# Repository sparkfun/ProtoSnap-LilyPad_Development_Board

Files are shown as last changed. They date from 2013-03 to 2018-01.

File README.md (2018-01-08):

ProtoSnap- LilyPad Development Board
====================================

LilyPad Protosnap

[*ProtoSnap-LilyPad Development Board (DEV-11262)*](https://www.sparkfun.com/products/11262)

The ProtoSnap LilyPad Development Board allows you to start prototyping in the world of e-textiles without a breadboard.

Repository Contents
-------------------
* **/Firmware** - LilyPad Development Board's default Arduino example code.
* **/Hardware** - All Eagle design files (.brd, .sch, .STL)

Documentation
-------------------
* [Hookup Guide](https://www.sparkfun.com/tutorials/308) - Basic hookup guide for the LilyPad Development Board.
* [Activity Guide](https://learn.sparkfun.com/tutorials/lilypad-development-board-activity-guide) - This guide will get you started with some introductory programming activities exploring each of the LilyPad pieces on the LilyPad Development Board. If you’ve never used Arduino to program before, this guide will walk you through the basics with example code to upload and explore.

Product Versions
----------------
* [DEV-11262](https://www.sparkfun.com/products/11262)- This is the standard ProtoSnap LilyPad Development Board
* [RTL-11261](https://www.sparkfun.com/products/11261)- Retail version of the ProtoSnap LilyPad Development Board. (Retired)
* [LAB-11762](https://www.sparkfun.com/products/11762)- Packaged version for educators teaching the ProtoShap LilyPad Development Board in a classroom setting. 

License Information
-------------------
The hardware is released under [Creative Commons Share-alike 3.0](http://creativecommons.org/licenses/by-sa/3.0/).

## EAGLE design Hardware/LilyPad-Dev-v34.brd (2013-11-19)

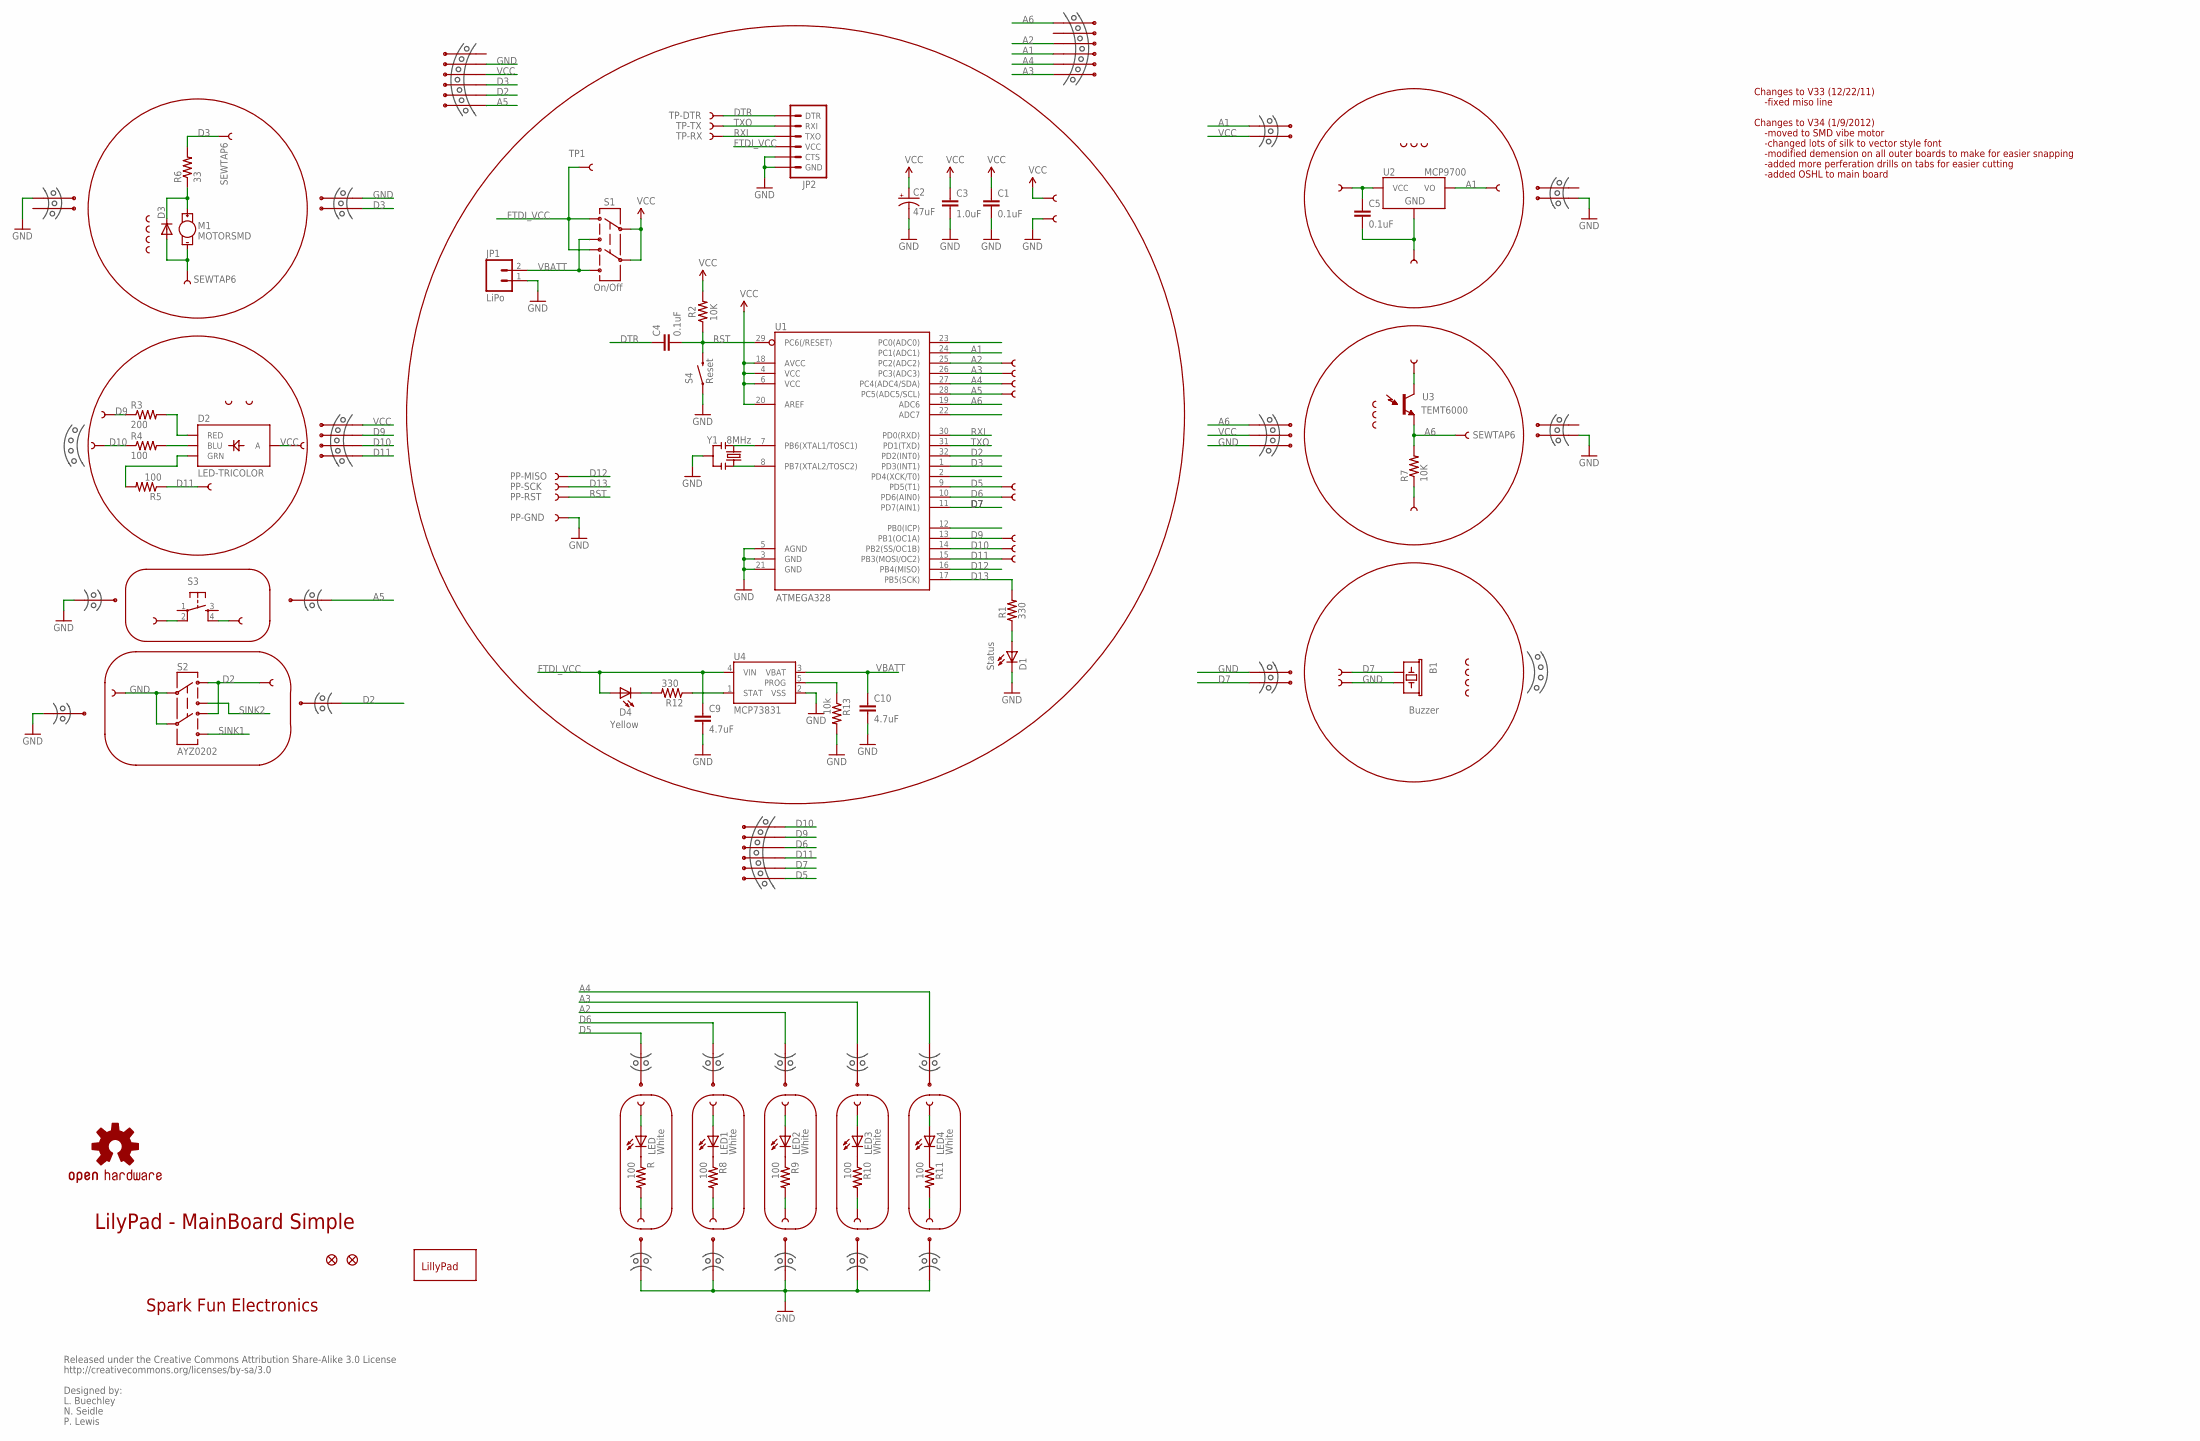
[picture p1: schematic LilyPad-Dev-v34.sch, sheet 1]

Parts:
1, 2, 3, 4: SEWTAP-NOHOLE2; PETAL-NOHOLE-2SIDE
A2/16, A3/17, A4/18, A5/19: SEWTAP9; PETAL-LONG-1-2SIDE
B1: Buzzer; BUZZER-CCV
BUTTON-: SEWTAP8; PETAL-SMALL
BUTTONS: SEWTAP8; PETAL-SMALL
C1, C4: 0.1uF; 0402-CAP
C2: 47uF; EIA3528
C3: 1.0uF; 0402-CAP
C5: 0.1uF; 0603-CAP
C9, C10: 4.7uF; 0402-CAP
D1: Status; LED-0603
D2: LED-TRICOLOR; LED-TRICOLOR-SMD
D3: DIODESOD; SOD-323
D4: Yellow; LED-0603
JP1: LiPo; JST-2-SMD
JP2: ARDUINO_SERIAL_PROGRAMSMD; 1X06-SMD
JP3, JP4: FIDUCIAL1X2; FIDUCIAL-1X2
LED, LED1, LED2, LED3, LED4: White; LED-1206
LED+, LED+1, LED+2, LED+3, LED+4: SEWTAP6; PETAL-SMALL-2SIDE
LED-, LED-1, LED-2, LED-3, LED-4: SEWTAP6; PETAL-SMALL-2SIDE
LIGHT1, LIGHT2, LIGHT3: SEWTAP-NOHOLE2; PETAL-NOHOLE-2SIDE
LIGHT+: SEWTAP6; PETAL-SMALL
LIGHT-: SEWTAP6; PETAL-SMALL
LIGHTS: SEWTAP6; PETAL-SMALL
LOGO: LOGO-LPLPA; LOGO-LPA
M1: MOTORSMD; VIBE-MOTOR-10MM-SMD
PP-GND: TEST-POINT3X5; PAD.03X.05
PP-MISO: TEST-POINT3X5; PAD.03X.05
PP-RST: TEST-POINT3X5; PAD.03X.05
PP-SCK: TEST-POINT3X5; PAD.03X.05
R, R8, R9, R10, R11: 100; 0603-RES
R1, R12: 330; 0402-RES
R2, R7: 10K; 0402-RES
R3: 200; 0402-RES
R4, R5: 100; 0402-RES
R6: 33; 0402-RES
R13: 10k; 0402-RES
S1: On/Off; AYZ0202
S2: AYZ0202
S3: TAC_SWITCHSMD; TACTILE_SWITCH_SMD
S4: Reset; TACTILE_SWITCH_SMD
SLIDEOFF: SEWTAP8; PETAL-SMALL
SLIDEON: SEWTAP8; PETAL-SMALL
TEMP1, TEMP2, TEMP3: SEWTAP-NOHOLE2; PETAL-NOHOLE-2SIDE
TEMP+: SEWTAP6; PETAL-SMALL
TEMP-: SEWTAP6; PETAL-SMALL
TEMPS: SEWTAP6; PETAL-SMALL
TP1: TEST-POINT3X5; PAD.03X.05
TP-DTR: TEST-POINT3X5; PAD.03X.05
TP-RX: TEST-POINT3X5; PAD.03X.05
TP-TX: TEST-POINT3X5; PAD.03X.05
U1: ATMEGA328; TQFP32-08
U2: MCP9700; SOT23-3
U3: TEMT6000; TEMT6000-SEN
U4: MCP73831; SOT23-5
U$1, U$4, U$37, U$39, U$41, U$43, U$45: SEWTAP9; PETAL-LONG-1-2SIDE
U$2, U$3, U$5, U$6, U$32, U$47: MOUSE-BITE-2
U$7, U$8, U$51: MOUSE-BITE-66; MOUSE-BITE-6
U$10, U$11, U$12, U$13, U$14, U$15, U$16, U$17, U$18, U$19, U$40, U$42, U$44, U$46: MOUSE-BITE-12_HOLES; MOUST-BITE-1-(2_HOLES)
U$20: MOUSE-BITE-4
U$22, U$23, U$24, U$25: SEWTAP6; PETAL-SMALL-2SIDE
U$26, U$27: SEWTAP-NOHOLE2; PETAL-NOHOLE-2SIDE
U$32-, U$33+: SEWTAP6; PETAL-SMALL
U$33: MOUSE-BITE-3
U$48, U$49: MOUSE-BITE-3(NO_PADS)
U$52: OSHW-LOGOS; OSHW-LOGO-S
VIBE1, VIBE2, VIBE3, VIBE4: SEWTAP-NOHOLE2; PETAL-NOHOLE-2SIDE
VIBE+: SEWTAP6; PETAL-SMALL
VIBE-: SEWTAP6; PETAL-SMALL
Y1: 8MHz; RESONATOR-SMD

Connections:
A1: TEMPS.1, U1.24 (PC1(ADC1)), U2.2 (VO), U$2.P$1, U$7.P$4
A2: A2/16.1, U1.25 (PC2(ADC2)), U$7.P$3, U$12.P$1
A3: A3/17.1, U1.26 (PC3(ADC3)), U$7.P$6, U$13.P$1
A4: A4/18.1, U1.27 (PC4(ADC4/SDA)), U$7.P$5, U$14.P$1
A5: A5/19.1, BUTTONS.1, S3.2, U1.28 (PC5(ADC5/SCL)), U$8.P$1, U$40.P$1
A6: LIGHTS.1, R7.2, U1.19 (ADC6), U3.EMITTER (E1), U$7.P$1, U$33.P$1
BLU: D2.B (BLU), R4.2
D2: S2.3 (1), S2.6 (4), SLIDEON.1, U1.32 (PD2(INT0)), U$8.P$2, U$46.P$1
D3: R6.2, U1.1 (PD3(INT1)), U$5.P$1, U$8.P$3, VIBE+.1
D5: U1.9 (PD5(T1)), U$10.P$1, U$41.1, U$51.P$1
D6: U1.10 (PD6(AIN0)), U$1.1, U$11.P$1, U$51.P$4
D7: B1.+ (1), U1.11 (PD7(AIN1)), U$32.P$2, U$33+.1, U$51.P$2
D9: R3.1, U1.13 (PB1(OC1A)), U$20.P$3, U$22.1, U$37.1, U$51.P$5
D10: R4.1, U1.14 (PB2(SS/OC1B)), U$20.P$2, U$24.1, U$39.1, U$51.P$6
D11: R5.1, U1.15 (PB3(MOSI/OC2)), U$4.1, U$20.P$1, U$23.1, U$51.P$3
D12: PP-MISO.P$1, U1.16 (PB4(MISO))
D13: PP-SCK.P$1, R1.2, U1.17 (PB5(SCK))
DTR: C4.1, JP2.1 (DTR), TP-DTR.P$1
FTDI_VCC: C9.1, D4.A, JP2.4 (VCC), S1.3 (1), S1.6 (4), TP1.P$1, U4.4 (VIN)
GND: B1.- (2), BUTTON-.1, C1.2, C2.C (-), C3.2, C5.2, C9.2, C10.2, D1.C, D3.2 (A), JP1.1, JP2.5 (CTS), JP2.6 (GND), LIGHT-.1, M1.P$2 (-), PP-GND.P$1, R7.1, R13.2, S2.2, S2.5, S3.4, S4.1, SLIDEOFF.1, TEMP-.1, U1.3 (GND), U1.5 (AGND), U1.21 (GND), U2.3 (GND), U4.2 (VSS), U$3.P$1, U$5.P$2, U$6.P$1, U$8.P$5, U$15.P$1, U$16.P$1, U$17.P$1, U$18.P$1, U$19.P$1, U$32.P$1, U$32-.1, U$33.P$3, U$42.P$1, U$43.1, U$44.P$1, U$47.P$1, VIBE-.1, Y1.2
GRN: D2.G (GRN), R5.2
unnamed: U1.7 (PB6(XTAL1/TOSC1)), Y1.1
unnamed: D1.A, R1.1
unnamed: U1.8 (PB7(XTAL2/TOSC2)), Y1.3
unnamed: D3.1 (C), M1.P$1 (+), R6.1
unnamed: LED.C, R.1
unnamed: LED.A, LED+.1
unnamed: LED-.1, R.2
unnamed: LED1.C, R8.1
unnamed: LED1.A, LED+1.1
unnamed: LED-1.1, R8.2
unnamed: LED2.C, R9.1
unnamed: LED2.A, LED+2.1
unnamed: LED-2.1, R9.2
unnamed: LED3.C, R10.1
unnamed: LED3.A, LED+3.1
unnamed: LED-3.1, R10.2
unnamed: LED4.C, R11.1
unnamed: LED4.A, LED+4.1
unnamed: LED-4.1, R11.2
unnamed: D4.C, R12.2
PROG: R13.1, U4.5 (PROG)
RED: D2.R (RED), R3.2
RST: C4.2, PP-RST.P$1, R2.1, S4.3 (2), U1.29 (PC6(/RESET))
RXI: JP2.3 (TXO), TP-RX.P$1, U1.30 (PD0(RXD))
SINK1: S2.4 (6)
SINK2: S2.1 (3)
STAT: R12.1, U4.1 (STAT)
TXO: JP2.2 (RXI), TP-TX.P$1, U1.31 (PD1(TXD))
VBATT: C10.1, JP1.2, S1.1 (3), S1.4 (6), U4.3 (VBAT)
VCC: C1.1, C2.A (+), C3.1, C5.1, D2.A, LIGHT+.1, R2.2, S1.2, S1.5, TEMP+.1, U1.4 (VCC), U1.6 (VCC), U1.18 (AVCC), U1.20 (AREF), U2.1 (VCC), U3.COLLECTOR (C1), U$2.P$2, U$8.P$4, U$20.P$4, U$25.1, U$33.P$2, U$45.1

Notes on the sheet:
LilyPad - MainBoard Simple
Spark Fun Electronics
Released under the Creative Commons Attribution Share-Alike 3.0 License
http://creativecommons.org/licenses/by-sa/3.0
Designed by:
L. Buechley
N. Seidle
P. Lewis
Changes to V33 (12/22/11)
-fixed miso line
Changes to V34 (1/9/2012)
-moved to SMD vibe motor
-changed lots of silk to vector style font
-modified demension on all outer boards to make for easier snapping
-added more perferation drills on tabs for easier cutting
-added OSHL to main board

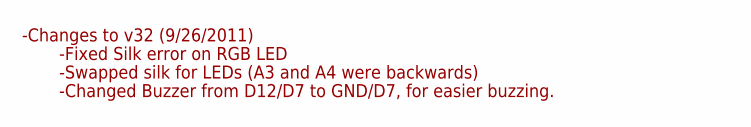
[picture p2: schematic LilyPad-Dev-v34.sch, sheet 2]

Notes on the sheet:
-Changes to v32 (9/26/2011)
-Fixed Silk error on RGB LED
-Swapped silk for LEDs (A3 and A4 were backwards)
-Changed Buzzer from D12/D7 to GND/D7, for easier buzzing.

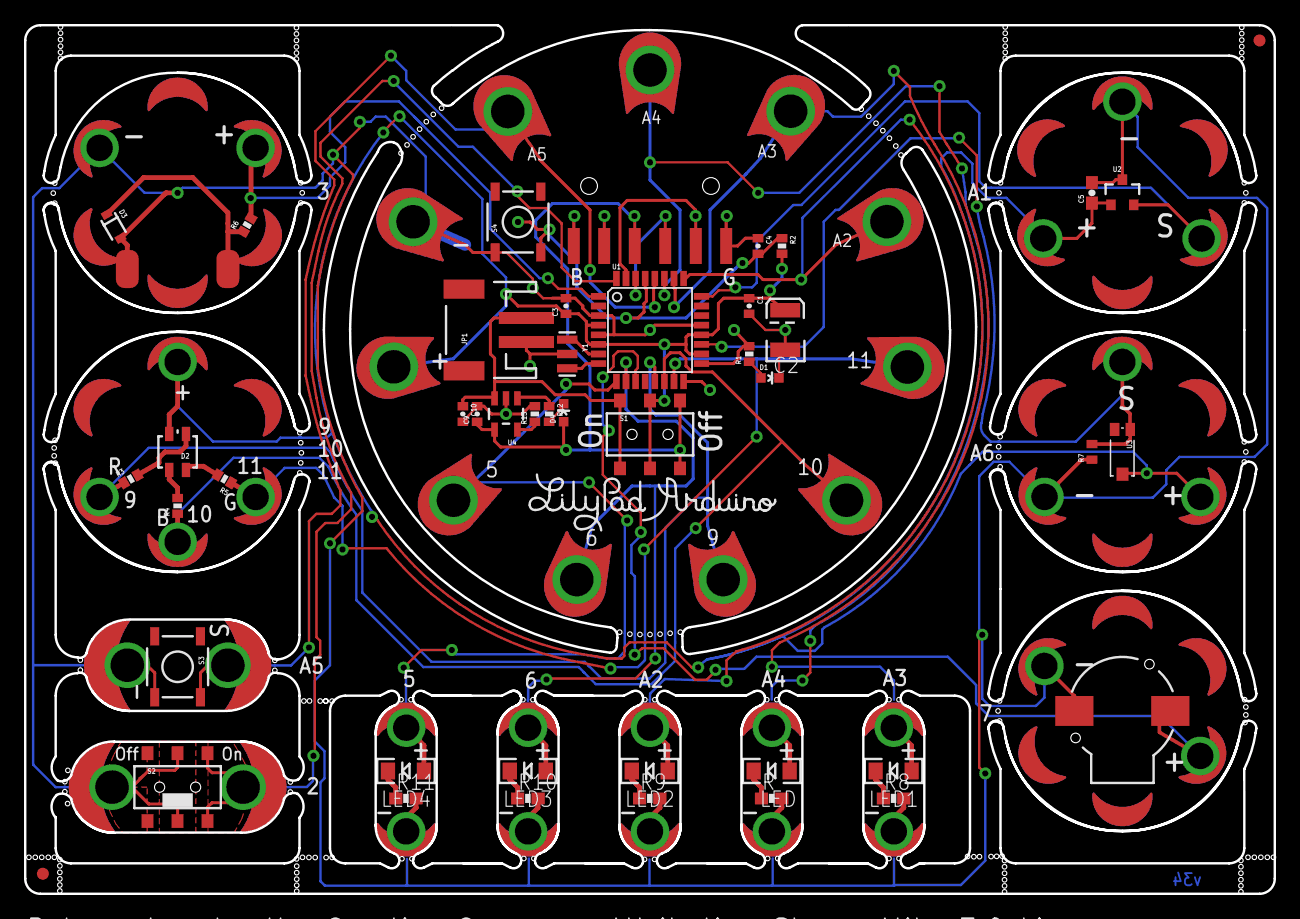
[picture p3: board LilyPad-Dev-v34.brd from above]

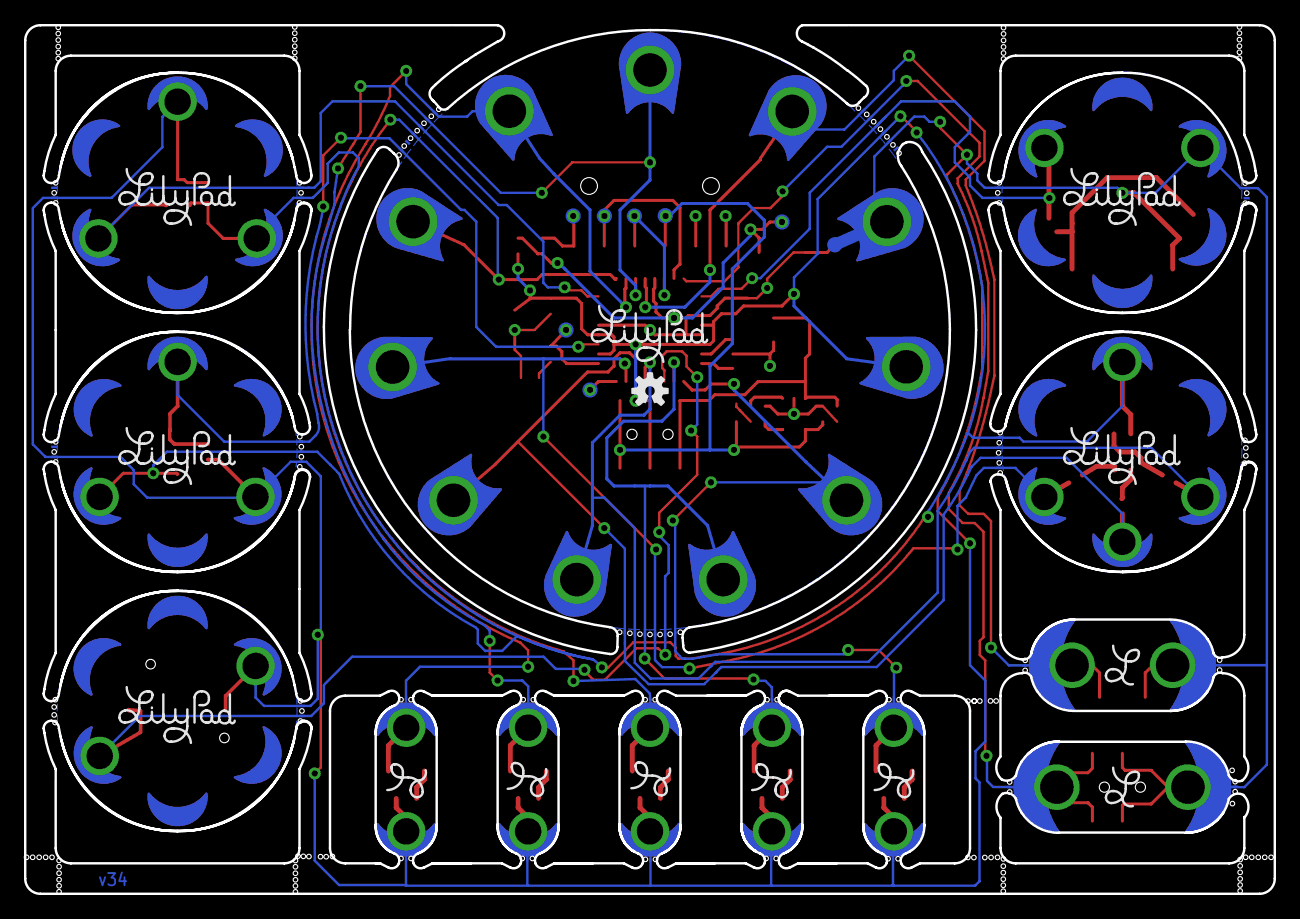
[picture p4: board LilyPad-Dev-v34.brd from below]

Board: 2 copper layers, 104.1 x 72.4 mm, 155 parts (22 on the bottom side), 49 nets.

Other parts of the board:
LOGO1, LOGO2, LOGO3, LOGO4, LOGO5, LOGO6, LOGO7: LOGO-LPL; LOGO-L
U$9: LOGO-LILYPAD
U$21, U$29, U$30, U$31, U$35: LOGO-LPLP; LOGO-LILYPAD
U$28, U$34, U$36, U$38, U$50: LILYPAD-BRD-LAYERS-SMALL

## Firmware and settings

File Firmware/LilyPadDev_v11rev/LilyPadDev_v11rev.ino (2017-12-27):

/* ProtoSnap LilyPad Development Platform Example Code
  by: Pete Lewis
      SparkFun Electronics
  date: 8/24/11
  license: Creative Commons Attribution-Share-alike v3.0 CC BY-SA 3.0
  http://creativecommons.org/licenses/by-sa/3.0/
  
  This is example code for the Protosnap LilyPad Development Platform
  It'll do a quick startup sequence, flashing all LEDs, then it'll go int the loop.
  In the loop it'll check for button or switch presses, and buzz or vibrate
  depending on if they're engaged.
  If neither switch is on, it'll check the light sensor and temperature sensor,
  and light up some LEDs if the proper values are met. Hold your finger over the
  light sensor to turn the white LEDs on. Try blowing on the temperature sensor to
  turn the red LED on.
  Finally, the status of each input is streamed over the serial line at 9600 bps.
  To see what the values are, open up the serial monitor (the top right icon)
  and make sure the baud is set to 9600.
*/

/* Pin Definitions */
// LEDs: white LEDs are connected to 5, 6, A2, A3, A4
int ledPins[] = {5, 6, A2, A4, A3, 9, 10, 11};
int switchPin = 2;
int buttonPin = A5;
int vibePin = 3;
int buzzerP = 7;
int buzzerN = 12;
int lightSensorPin = A6;
int tempSensorPin = A1;

/* Global variables */
int light = 100;

void setup()
{
  //STARTUP LED SEQUENCE
  for(int i=0; i<5; i++)  // This for loop will run 5 times
  {  // blink the white LEDs (first 5 LEDs in ledPins array)
    pinMode(ledPins[i], OUTPUT);  // set pin as output
    digitalWrite(ledPins[i], HIGH);  // turn LED on
    delay(250);  // wait for a quarter second
    digitalWrite(ledPins[i], LOW); // turn LED off
  }
  for(int i=5;i<8;i++)  // This for loop will run 3 times
  {   // blink the RGB LEDs (last 3 LEDs in ledPins array)
    pinMode(ledPins[i], OUTPUT);   // set the pin as an output 
    digitalWrite(ledPins[i], LOW);  // turn RGB LED on
    delay(250);  // wait a quarter second
    digitalWrite(ledPins[i], HIGH);  // turn the RGB LED off
    // Note that a HIGH turns the RGB LED off, LOW is on
    // that's backwards from the white LEDs
  }
  ////////////////////////////////////////////

  //Switch
  pinMode(switchPin, INPUT_PULLUP);  // set the switch as an input and use internal pullup resistors

  //Button
  pinMode(buttonPin, INPUT_PULLUP);  // set the pin as an input and use internal pullup resistors

  //VIBE
  pinMode(vibePin, OUTPUT);  // set the pin as an output

  //Buzzer
  pinMode(buzzerP, OUTPUT);  // set both buzzer pins as outputs
  pinMode(buzzerN, OUTPUT);

  Serial.begin(9600);  // We'll output some information over serial
}

void loop()
{
  //Buzzer
  if(digitalRead(buttonPin) == 0)
  {  // if you press the button, make a short buzz
    digitalWrite(buzzerP, HIGH);
    digitalWrite(buzzerN, LOW);
    delay(1);
    digitalWrite(buzzerP, LOW);
    digitalWrite(buzzerN, HIGH);
  }
  else  // If the button is not pressed go in here
  {
    if(digitalRead(switchPin) == 0)
    {  // If the switch is on, vibrate
      digitalWrite(vibePin, HIGH);
      delay(100);
      digitalWrite(vibePin, LOW); 
    }
    
    ///LIGHT TEST
    if(analogRead(lightSensorPin) < 20){
      //if its dark, turn on all white leds...
      for(int i=0;i<5;i++)
      {
        digitalWrite(ledPins[i], HIGH);
      }
    }
    else{
      // if it's light, turn them off...
      for(int i=0;i<5;i++)
      {
        digitalWrite(ledPins[i], LOW);
      }
    }

    ///TEMP TEST 
    if(analogRead(tempSensorPin) > 160)
    {
      //if the tech puts a little hot air over the temp sensor it will raise to at least 170
      digitalWrite(ledPins[5], LOW); //Turn on red LED - to indicate "hot"
    }
    else{
      digitalWrite(ledPins[5], HIGH);  // turn the red LED off
    }
    
    /* from here on down, we'll just print out the status of every input */
    Serial.print("Switch=");
    Serial.print(digitalRead(switchPin));

    Serial.print("  Temp=");
    Serial.print(analogRead(tempSensorPin));
    
    Serial.print("  Button=");
    Serial.print(digitalRead(buttonPin));

    Serial.print("  Light=");
    Serial.println(analogRead(lightSensorPin)); 
  }
}

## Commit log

2013-03-25 Files as being sent out for prototype.
    Moved a bunch of components to 0603.
    Had to move a lot of components just slightly and re-route traces.
    [ProtoSnap-LilyPad_Development_Board.brd, ProtoSnap-LilyPad_Development_Board.sch]
2013-11-19 Adding current board files
    [LilyPad-Dev-v34.brd, LilyPad-Dev-v34.sch]
2017-12-20 Create lilypad_dev_v11.ino
    -Adding Pete Lewis' default example code for the LilyPad ProtoSnap Development Board that is linked in SparkFun's old tutorials [ [https://www.sparkfun.com/tutorials/308](https://www.sparkfun.com/tut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
    -Converting .pde to .ino
2017-12-27 Update lilypad_dev_v11.ino
    Combine old method of setting a button/switch HIGH for a pull-up [ [https://www.arduino.cc/en/Tutorial/DigitalPins](https://www.arduino.cc/en/Tutorial/DigitalPins) ]:
    //Switch
    pinMode(switchPin, INPUT); // set the switch as an input
    digitalWrite(switchPin, HIGH); // enable the pull-up resistor
    //Button
    pinMode(buttonPin, INPUT); // set the pin as an input
    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

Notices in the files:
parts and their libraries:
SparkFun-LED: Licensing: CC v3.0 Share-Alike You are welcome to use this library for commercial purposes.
